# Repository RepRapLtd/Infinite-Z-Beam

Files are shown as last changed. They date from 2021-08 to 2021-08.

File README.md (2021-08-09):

# A 3D printed beam that is as stiff as steel

A while ago [Naomi Wu 机械妖姬](https://en.wikipedia.org/wiki/Naomi_Wu) very kindly sent us one of [Creality](https://www.creality.com/)'s infinite-Z belt printers. Lots of people have printed long <span style="font-family: 'times new roman', times, serif;">I</span> beams on this type of machine, but we thought that we'd write a Python [FreeCAD](https://www.freecadweb.org/) program to generate parametric beams more suitable for 3D printing, taking advantage of the fact that complexity is more or less free with this technology and that infinite-Z belt printers can print many overhanging shapes without support material. The result is a beam that is about as stiff as a steel beam of the same weight. 

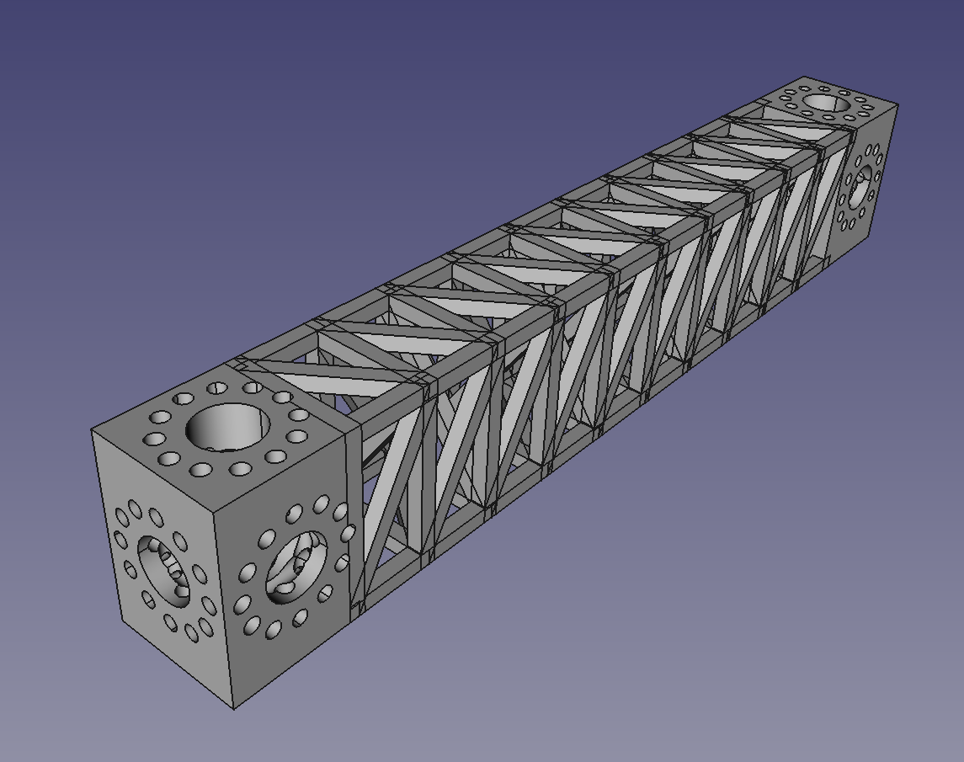
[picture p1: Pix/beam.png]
 

The image above shows an example of the Python output. All you need to specify is the length, width, and height, the thickness of the struts, and the diameter and number of the screw holes in the mounting blocks at the ends. The program then automatically generates the entire beam. 

The central section consists of a row of open boxes, each of which is decomposed into tetrahedra. This effectively means that the entire shape is built from tetrahedra - the strongest shape - and also that most of the material is on the outer faces which gives a high second-moment of cross-sectional area for bending resistance in all directions.  The diagonals are angled so that a belt printer with a 45<sup>o</sup> Z movement can print the entire structure without support material. 

The blocks at the ends are for bolting the beams to each other or to other items. The rings of 12 small holes shown allow any orientation in increments of 30<sup>o</sup>. The large holes are to allow wiring, tubes and other services to be run down the middle of the beams and connect up at the ends, or to allow things such as drive shafts to be accommodated. 

It turns out that FreeCAD can't model the rings of small holes. If you want to skip a technical explanation of why this is so then just know that there's a work-round and ignore the italic section that follows. 

*The image below shows the shape of all the small holes that needs to be subtracted from the end blocks.*

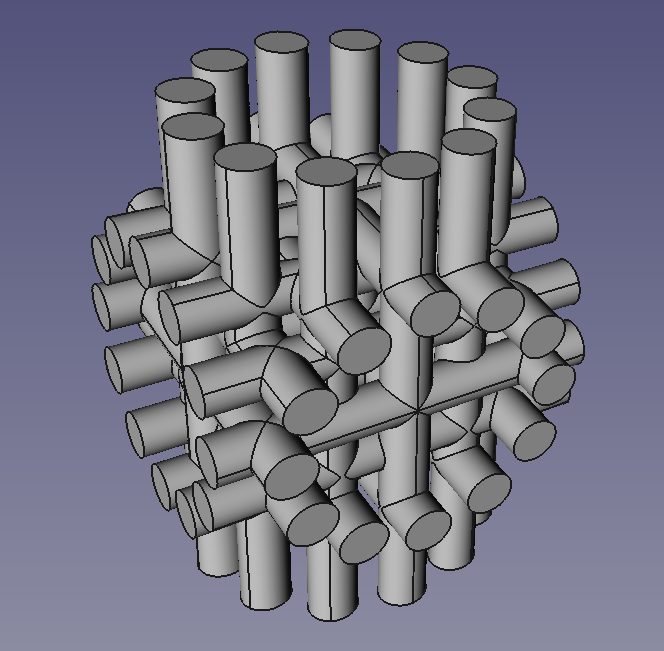
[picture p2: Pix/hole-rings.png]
</span> 

*As you can see, there are a lot of common tangencies where cylinders cross. When FreeCAD throws the calculation of these to <span style="color: #339966;">[Open Cascade](https://www.opencascade.com/products/cad-assistant/)</span>, which is the geometric modeller that FreeCAD uses to represent shapes, it goes away and gets lost in its own thoughts (CPU: 100%...) and you never hear from it again. I (Adrian) don't think this is really a bug in Open Cascade; any <span style="color: #339966;">[boundary-representation (B-rep) geometric modeller](https://en.wikipedia.org/wiki/Boundary_representation)</span> would probably have the same problem. Because (as the name implies) B-rep modellers represent shapes by recording the topology and geometry of their surfaces, they have to put a lot of effort into doing things like working out the curves of intersection between surfaces, and keeping all the shape topology consistent while this is done. In some cases this is quite literally impossible. For example there is no <span style="color: #339966;">[closed-form solution](https://en.wikipedia.org/wiki/Closed-form_expression)</span> to working out the curve of intersection between two <span style="color: #339966;">[NURBS surfaces](https://en.wikipedia.org/wiki/Non-uniform_rational_B-spline)</span>; that always has to be approximated. Even for cylinder-cylinder intersections, things can get complicated (look at the topological stitch-lines running along the cylinders in the picture; these all have to be matched up).*

*[Set-theoretic (or CSG) geometric modellers</span>](https://en.wikipedia.org/wiki/Constructive_solid_geometry) have none of these problems because they don't represent the surfaces of objects; they represent their solidity. In their simplest form they can only answer one question: given a point (x, y, z), is it **inside** the solid part of the object or **outside**? - a so-called membership test. (In practice set-theoretic modellers can all do much more than this.) And they do membership-tests with rock-solid certainty. Unfortunately they are rarely used in CAD systems, except as a means of input. The reasons for this are historical rather than technical. For example the invention of the hardware [depth-buffer](https://en.wikipedia.org/wiki/Z-buffering), which allows computer graphics systems to make pictures of large numbers of triangles blindingly fast, favoured the early development of systems that represent surfaces (which are easy to triangulate). If instead a hardware [ray-tracer](https://en.wikipedia.org/wiki/Ray_tracing_(graphics)) had been implemented, then set-theoretic modellers (which are natural choices for ray tracing) might have come to dominate. (I wrote a <span style="color: #339966;">[set-theoretic modeller called SvLis](https://github.com/AdrianBowyer/SvLis)</span> in C++ about three decades ago; if you want to go mad see if you can get it going with a modern C++ compiler. If you succeed, <span style="color: #339966;">[DM me](https://reprapltd.com/contact-us/)</span>...)*

*The work-round in FreeCAD that allows the cylinders to be dealt with is as simple as it is nasty. The cylinder radii are perturbed a tiny bit at random:*

<span style="font-family: 'courier new', courier, monospace; color: #800000;">cyl = Part.makeCylinder(d/2 + random.uniform(-0.01, 0.01), z + 0.2)</span>

*This means that what were common tangencies no longer are, quite . The perturbation is well below the resolution of 3D printing.*

The following image shows the beams being printed in PLA. 

 

When it was done, we subjected one to a bending test using weights and a dial gauge to measure deflection. 

(https://reprapltd.com/wp-content/uploads/2021/08/bending-test-1.jpg) 

Note the pieces of wood on the left; if only we had some way to 3D-print structural parts... 

The beam was held and deflected sideways so it couldn't slip in the vice. Here are the results: 

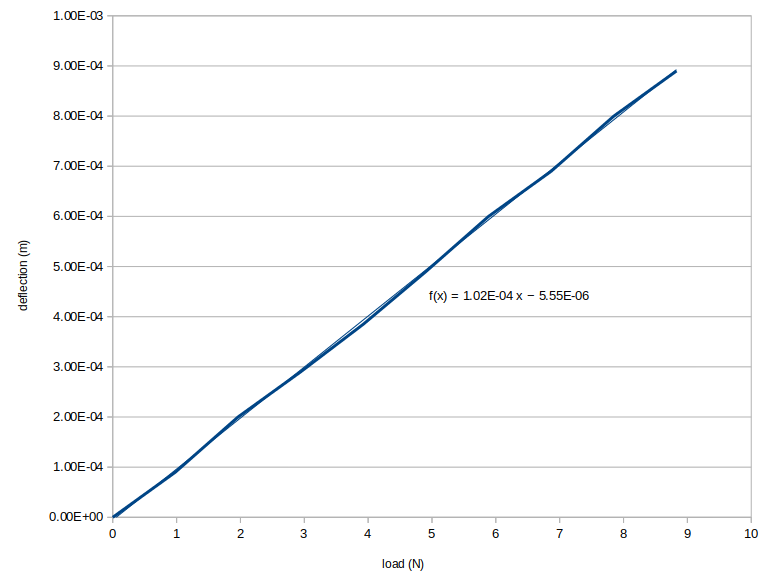
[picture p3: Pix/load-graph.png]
 

The equation is that of the least-squares fit straight line. The effective length of the beam (ignoring the clamped end) was 175 mm. Its stiffness was 1.02 x 10<sup>-4</sup> mN<sup>-1</sup> from the graph. This meant that its flexural rigidity (_EI_) was 17.5 Nm<sup>2</sup> (where _E_ is Young's modulus in Pa and _I_ is the second moment of area in m<sup>4</sup>). Thus we can work out that an equivalent steel beam would be 5 mm square. (That is to say, a steel beam with the same _EI_ value.) 

The printed beam weighed 47.7 grams. Coincidentally a 5 mm square steel beam of the same length (including the clamped end) would weigh about the same (47 grams), so we have made a printed beam that is about as stiff as the same weight of steel. 

The printed beam was physically bigger than its steel equivalent, of course. This is to be expected as PLA has a much lower elastic modulus than steel. But printing allows any size easily to be created, it allows services to be run up the insides, and it allows a fancy pattern of attachments and screw holes to be created at the ends, all automatically. 

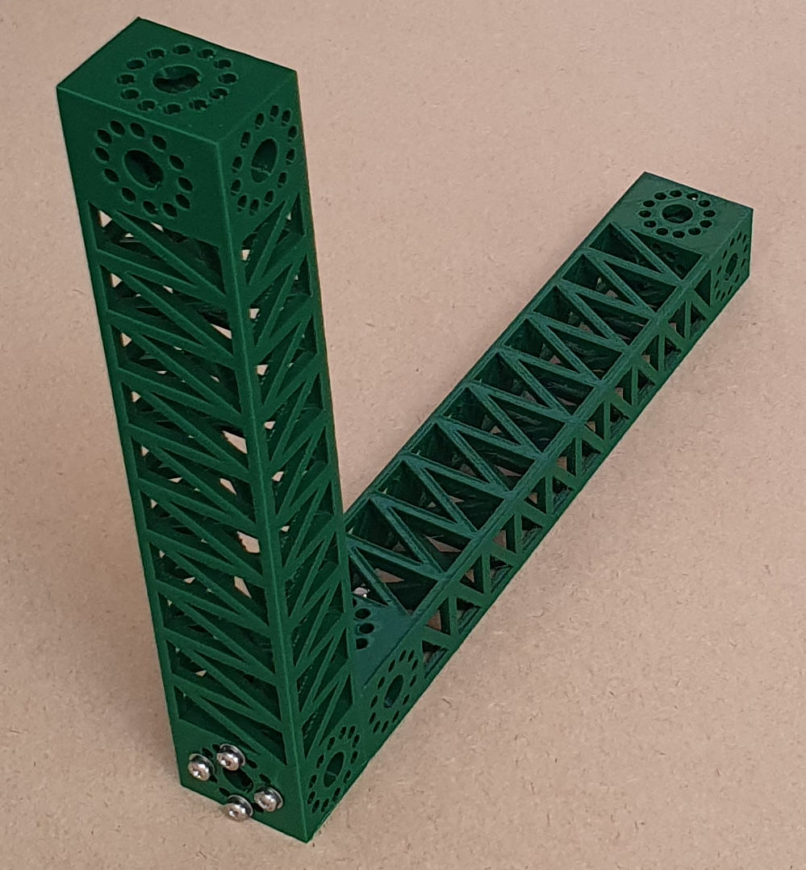
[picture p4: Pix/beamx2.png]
 

It would also allow a beam of beams to be printed. Because it needs no support, this beam design could be used as the struts of a much bigger beam in the same pattern. This would make a fractal beam... 

Our Python program that makes the beams in FreeCAD is in the **Software** directory of this repository in the file **square-beam.py**. The file **Z-beam.scad** is an [OpenSCAD](https://openscad.org/) set-theoretic (CSG) version by David Eccles that he did *a few hours after we released this*. **We all love open-source!**

It has not escaped our attention that beams of this sort would be ideal components for building a [RepRap](https://reprap.org/wiki/RepRap) infinite-Z belt printer.

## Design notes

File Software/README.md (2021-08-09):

# Software for the RepRap Ltd printed beam

The file square-beam.py is our (RepRap Ltd's) original.

Z-beam.scad is an OpenSCAD version by David Eccles (@gringene_bio).

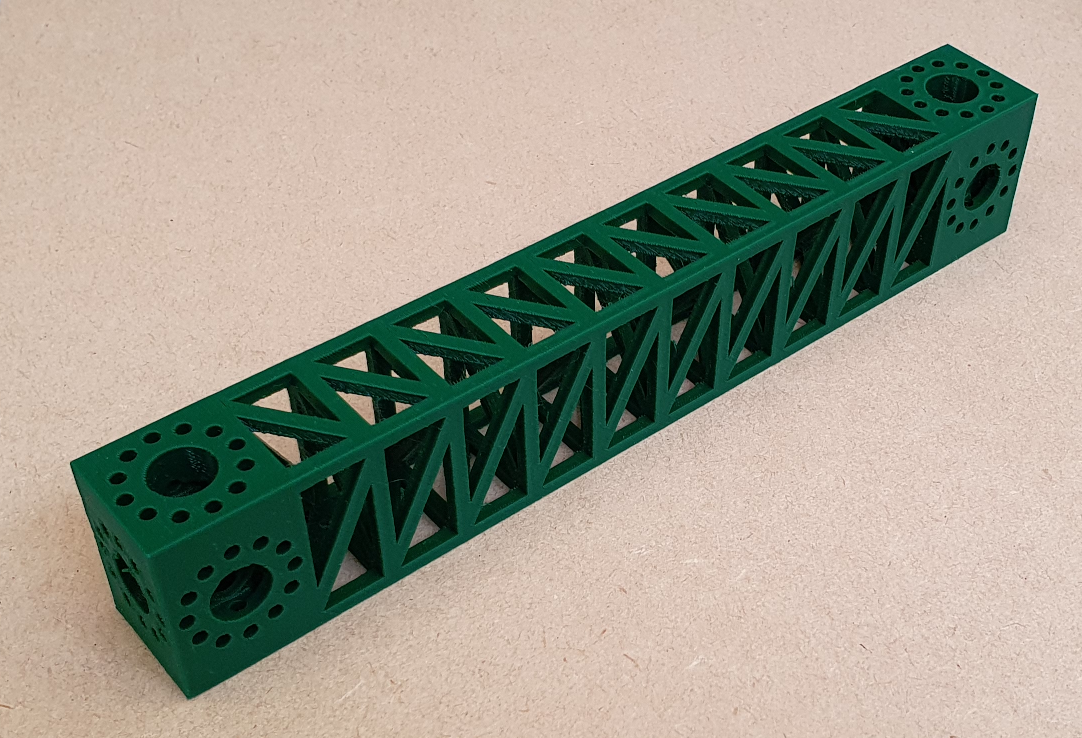
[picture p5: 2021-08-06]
Pix/finished-beam.png

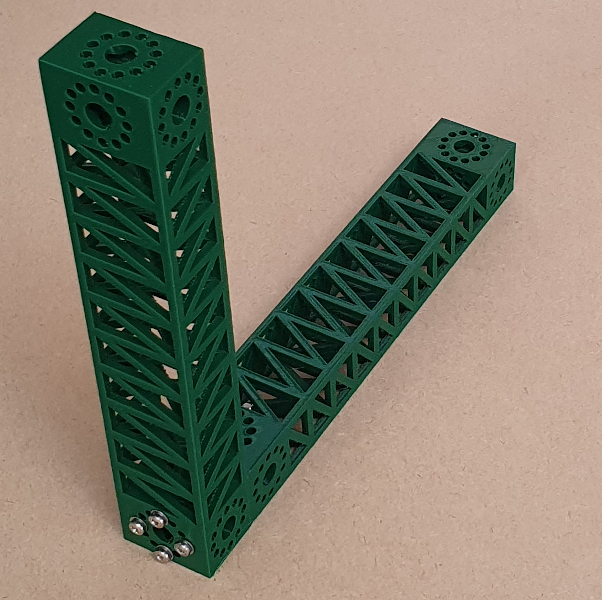
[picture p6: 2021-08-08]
Pix/beam-600.png

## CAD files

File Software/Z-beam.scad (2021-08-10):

// parametric beam with cable-running spaces
// ported to OpenSCAD from the Python code, with variable descriptions modified
// to be customizer-compatible
// see https://reprapltd.com/3d-printed-beam-that-is-as-stiff-as-steel/

// ---------------------------------------------------------------------------

// Set the values you want in here. All dimensions are in mm.

// The overall size of the beam. Length must be the biggest dimension.
// Note the beam will be reoriented to make the Z direction the larger of 
// width and height, as that is the orientation in which it must be printed.

// beam length; must be the biggest dimension
length = 200;
// width of the beam
width = 35;
// height of the beam
height = 25;

// The thickness of the beam struts
thickness = 3;

// The size of the mounting holes.
holeSize = 3;

// Number of mounting holes at each end 
screwHoleCount = 12;

// Style of diagonal struts
diagStyle = "tetra"; // ["tetra", "octa", "Z"]

// ---------------------------------------------------------------------------

// Internal parameters. Change these to get interesting, but possibly
// incorrect, results.

// [internal] box height as ratio of shortest dimension
angleFactor = 0.8;
// [internal] gap between screw holes
screwGap = 5;
// [internal] additional relative adjustment for screw spacing
screwPitch = 1.5;
// [internal] small adjustment to remove intersecting vertices
sigma = 0.01;
// [internal] additional size for hole cuts
holeDelta = 0.3;

// Create the beam

x = length;
y = min(height, width);
z = max(height, width);
boxStep1 = angleFactor * y;
boxLen = x + thickness - 2*y;
numSteps = floor(boxLen / (boxStep1 - thickness)) + 1;
boxStep = boxLen / numSteps;
xi = y - thickness;

// outline box
module OutlineBox(endForm = 3, flipDiags = false){
    if(endForm > 0){
      // top / bottom
      xtrans = 
        (endForm == 1) ? [0]:
        (endForm == 2) ? [boxStep]:
        (endForm == 3) ? [0, boxStep]: [];
      for(xtran = xtrans){
          translate([0,0,xtran]) linear_extrude(thickness) difference(){
              square([y,z]);
              offset(-thickness) square([y,z]);
          }
      }
    }
    // corner struts
    ssz = thickness / 2;
    strutStarts = [[0, 0,           ssz], [y-thickness, 0,           ssz],
                   [0, z-thickness, ssz], [y-thickness, z-thickness, ssz]];
    for(strutStart = strutStarts){
        translate(strutStart) cube([thickness, thickness, boxStep]);
    }
    // diagonals
    yol = y - 2 * thickness;
    zol = z - 2 * thickness;
    xol = boxStep - thickness;
    dlx = sqrt(yol*yol + zol*zol) + sigma;
    dly = sqrt(yol*yol + xol*xol) + sigma;
    dlz = sqrt(zol*zol + xol*xol) + sigma;
    diagMul1 = 
       (diagStyle == "Z") ?     [-1,  1, -1,  1,  1,  1] :
       (diagStyle == "tetra") ? [ 1, -1, -1,  1, -1, -1] :
       (diagStyle == "octa") ?  [ 1, -1, -1,  1, -1, -1] :
           [1, 1, 1, 1, 1, 1];
    diagMul = (flipDiags) ? diagMul1 * -1 : diagMul1;
    // left
    translate([y/2,0,(boxStep+thickness)/2])
        rotate([0,diagMul[0] * atan2(xol, yol)+90,0])
          translate([-thickness/2,0,-dly/2])
            cube([thickness, thickness, dly]);
    // right
    translate([y/2,z-thickness,(boxStep+thickness)/2])
        rotate([0,diagMul[1] * atan2(xol, yol)+90,0])
          translate([-thickness/2,0,-dly/2])
            cube([thickness, thickness, dly]);
    // front
    translate([0,z/2,(boxStep+thickness)/2])
        rotate([diagMul[2] * atan2(xol, zol)+90,0,0])
          translate([0,-thickness/2,-dlz/2])
            cube([thickness, thickness, dlz]);
    // back
    translate([y-thickness,z/2,(boxStep+thickness)/2])
        rotate([diagMul[3] * atan2(xol, zol)+90,0,0])
          translate([0,-thickness/2,-dlz/2])
            cube([thickness, thickness, dlz]);
    // internal bottom
    if((endForm == 1) || (endForm == 3)){
      translate([y/2, z/2, thickness/2])
        rotate(diagMul[4] * atan2(zol, yol)+90) rotate([90,0,0])
          translate([-thickness/2,-thickness/2,-dlx/2])
            cube([thickness, thickness, dlx]);
    }
    // internal top [not usually printed]
    if((endForm == 2) || (endForm == 3)){
      translate([y/2, z/2, boxStep + thickness/2])
        rotate(diagMul[5] * atan2(zol, yol)+90) rotate([90,0,0])
          translate([-thickness/2,-thickness/2,-dlx/2])
            cube([thickness, thickness, dlx]);
    }
}

module EndBlock(report=false){
  holeSizeAdj = holeSize + holeDelta;
  largeDiam = y - screwGap * (holeSizeAdj);
  pitchRadius = 0.5*round(2.0*(largeDiam/2 + 
                  screwPitch*(holeSizeAdj)));
  difference(){
    cube([y,z,y]);
    // large hole cuts
    translate([y/2,z/2,y/2]) {
      rotate([90,0,0]) cylinder(h=z*2, d=largeDiam, center=true, $fn=61);
      rotate([0,90,0]) cylinder(h=z*2, d=largeDiam, center=true, $fn=61);
      rotate([0,0, 0]) cylinder(h=z*2, d=largeDiam, center=true, $fn=61);
    }
    // screw hole cuts
    translate([y/2,z/2,y/2]) {
      rotate([90,0,0]) for(rti = [0:(screwHoleCount-1)]){
        rotate(rti * (360 / screwHoleCount)) translate([pitchRadius,0,0]){
          cylinder(d=holeSizeAdj, h=z*2, center=true, $fn=13);
        }
      }
      rotate([0,90,0]) for(rti = [0:(screwHoleCount-1)]){
        rotate(rti * (360 / screwHoleCount)) translate([pitchRadius,0,0]){
          cylinder(d=holeSizeAdj, h=z*2, center=true, $fn=13);
        }
      }
      for(rti = [0:(screwHoleCount-1)]){
        rotate(rti * (360 / screwHoleCount)) translate([pitchRadius,0,0]){
          cylinder(d=holeSizeAdj, h=z*2, center=true, $fn=13);
        }
      }
    }
  }
  // Tell the user what they need to know.
  if(report){
    echo(str("There are ", screwHoleCount, " screw holes for attachment with diameter ",
         holeSize," mm on a pitch circle of ", pitchRadius, " mm."));
  }
}

// bottom end block
EndBlock(report=true);

// struts
for(xi = [0 : numSteps-1]){
  translate([0,0,xi*boxStep-thickness+y])
    OutlineBox(endForm = ((xi == 0) ? 0 : 1),
               flipDiags = ((diagStyle=="octa") && (xi % 2 == 0)));
}

// top end block
translate([0,0,length-y]) EndBlock();

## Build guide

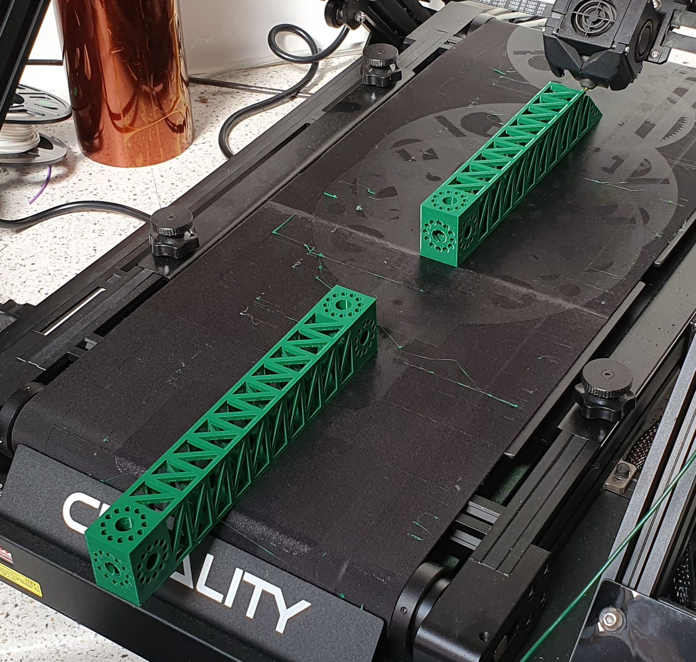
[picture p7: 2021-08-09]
Pix/beam-printing.png

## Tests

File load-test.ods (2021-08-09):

load (g) | Deflection (0.01mm) |  | Load (N) | Deflection(m)
0 | 0 |  | 0 | 0.00E+00
100 | 9 |  | 0.981 | 9.00E-05
200 | 20 |  | 1.962 | 2.00E-04
300 | 29 |  | 2.943 | 2.90E-04
400 | 38.5 |  | 3.924 | 3.85E-04
500 | 49 |  | 4.905 | 4.90E-04
600 | 60 |  | 5.886 | 6.00E-04
700 | 69 |  | 6.867 | 6.90E-04
800 | 80 |  | 7.848 | 8.00E-04
900 | 89 |  | 8.829 | 8.90E-04
Gradient (defln/N) |  | mass (kg)
1.02E-04 |  | 0.0477
Length (m)
0.175
EI
17.5142973856209
E(steel) Pa
2.10E+11
I(steel)
8.34014161220044E-11
steel width
0.005
steel height
0.005849627645161
steel volume
5.8496276451612E-06
steel density
8000
steel mass
0.04679702116129

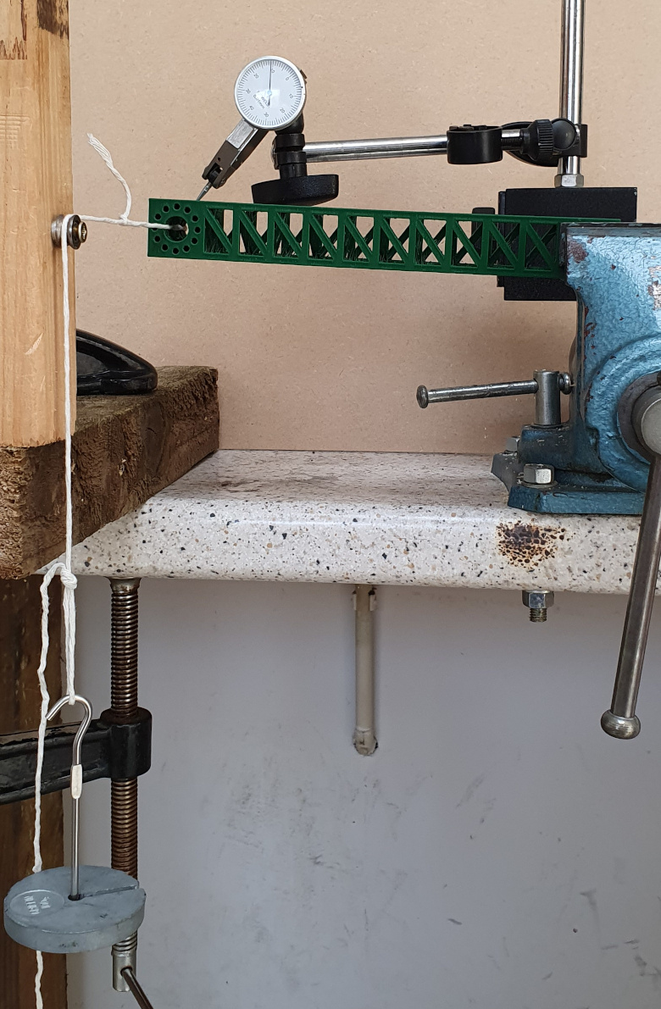
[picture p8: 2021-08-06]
Pix/bending-test.jpg

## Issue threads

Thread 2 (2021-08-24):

What is the orientation to print on a standard fdm printer?

foocross, 2021-08-24:
Sorry if I have missed this- but its unclear how to orient the model on a standard fdm printer. Any help would be appreciated.

RepRapLtd, 2021-08-25:
It may be difficult to print on a standard FFF printer without support because it was designed to take advantage of the way that belt printers can print horizontal overhangs. However, the best orientation on a standard FFF printer would be with the second longest dimension in the Z direction.

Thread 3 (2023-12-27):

What screws are used for combining the beams?

dov, 2023-12-27:
It would be great if the documentation included a description of what screws are used for connecting the beams. Is it self threading mechanical screws?

RepRapLtd, 2023-12-27:
Hi. If you look at the start of the Python code you'll see you can set this. Currently the holes are set to 3.3mm, which is right for M3 screws.

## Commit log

2021-08-06 First commit.
    [load-test.ods]
2021-08-06 State at blog post.
    [load-test.ods]
2021-08-07 Made hole ring count a user parameter.
2021-08-08 Bolted together pic added.
2021-08-09 Beam printing pic added.
2021-08-09 David Eccles version added.
    [Z-beam.scad]
2021-08-09 Small spreadsheet correction.
    [load-test.ods]
2021-08-10 Internal diagonal struts + diagonal customisation
    I've now added diagonal direction to the customisation, with the default set to the tetrahedral structure. There are three options:
    * tetra - tetrahedral structure
    * octa - split octahedral structure (alternately flipped layers)
    * Z - "Z" shape on each face
    [Z-beam.scad]
2021-08-10 Eccles beam updated.
    [Z-beam.scad]
